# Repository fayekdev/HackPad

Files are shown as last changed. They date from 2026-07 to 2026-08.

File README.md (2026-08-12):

# **.devPAD**

An Elevated "SteamDeck" for developpers with fully customizable controls across many programs. I made it to make my life easier by having all of the most used tools and a way to properly move in CAD using the joystick in the middle. The e-ink screen is used as clock and a to-do list and could display the current media, volume level, microphone status and temperature.

***the tech stack***

 







## Screenshots

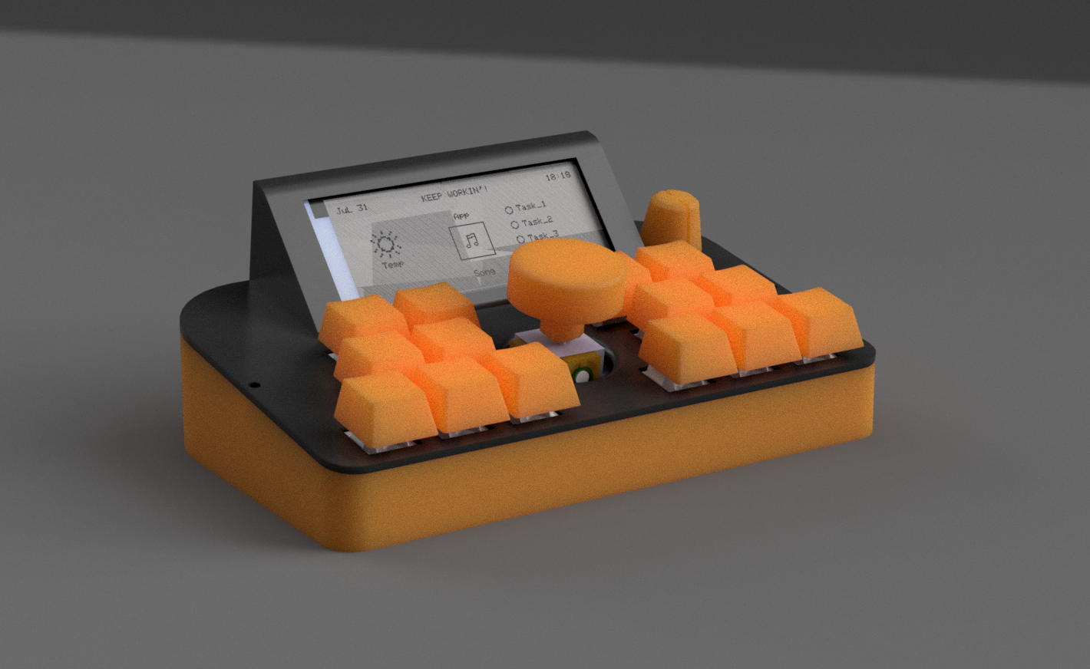
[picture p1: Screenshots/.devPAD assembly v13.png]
Render


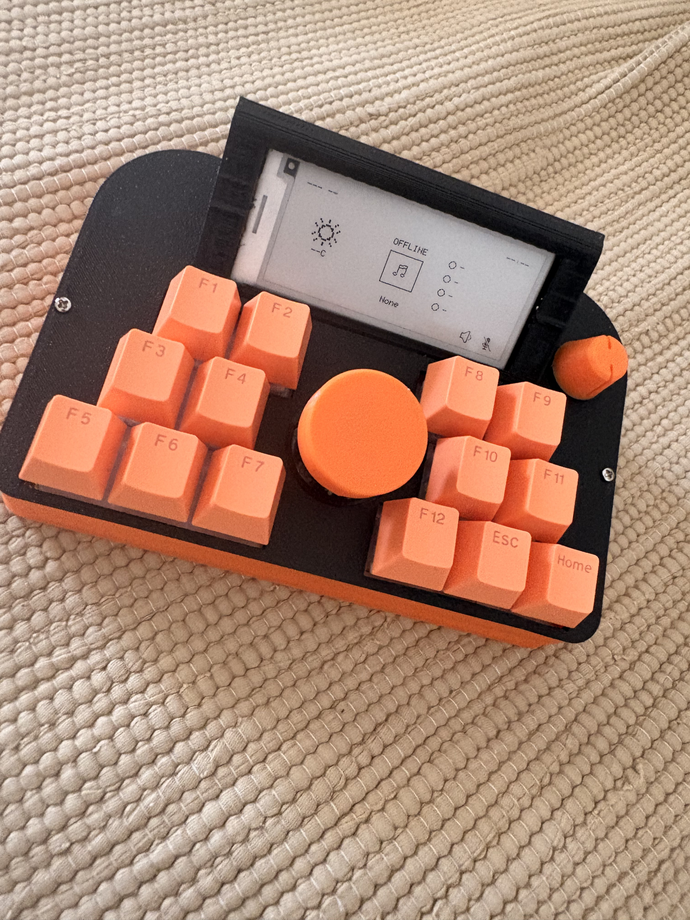
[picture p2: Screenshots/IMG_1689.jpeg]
Physical


## *THE CODE*

The code is still incomplete but still has ~80% functionality(only a few minor changes to make)

Currently working on the hardware problems so it is on delay

## *How was it made*  

- I designed the PCB in KiCAD and exported to Fusion to model the Case.

- The case was modeled and the components too to ensure the fit is correct

- Printed the first version 

- Fixed the errors in V1 and added a few features. 

- The PCB arrived and all components were test fit

- Began soldering the PCB 

- Fixed the errors I had made and uploaded a few test sketches.

- Test sketches were success and I tested the production code

- Production code worked out fine with a few problems

- A wire connected the screen to the microcontroller snapped and when trying to fix it a short-circuit happened and probably caused the microcontroller to malfunction.

*(The device only worked for 30 minutes or so before breaking)*

## *AI disclosure*

- AI was used as a research tool where I gave it all my requirements in one and it generated some sort of documentation that was held in it's context window so that when I ask a question or have a concern it automatically gives the answer I need instead of losing a ton of time researching myself

- Another usecase is the few errors I stumble upon that I spent a ton of time trying to fix I give to AI to give me a suggestion on how to fix it 

## Installation

Install the .devPAD desktop app --> 



Upload the **main.ino** sketch to the microcontroller

**SCREENSHOTS OF THE APP**

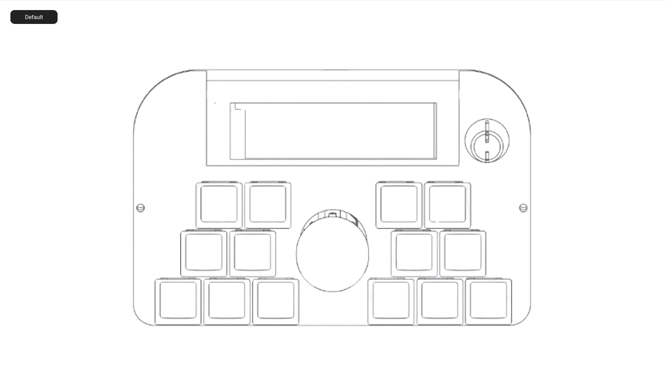
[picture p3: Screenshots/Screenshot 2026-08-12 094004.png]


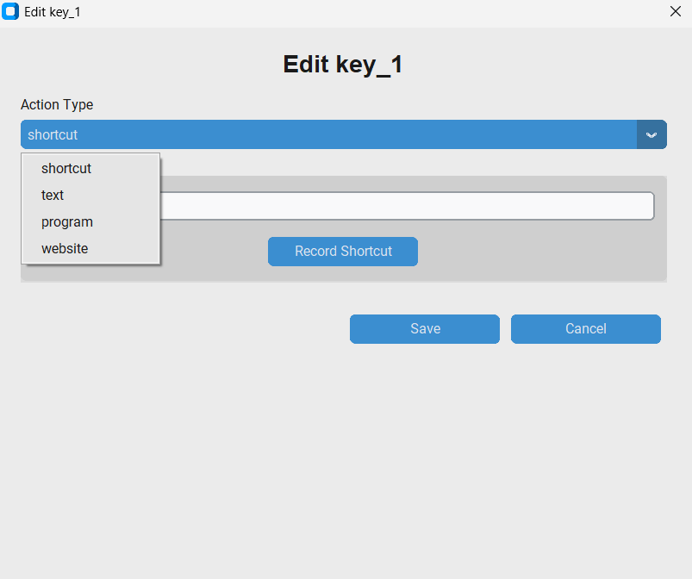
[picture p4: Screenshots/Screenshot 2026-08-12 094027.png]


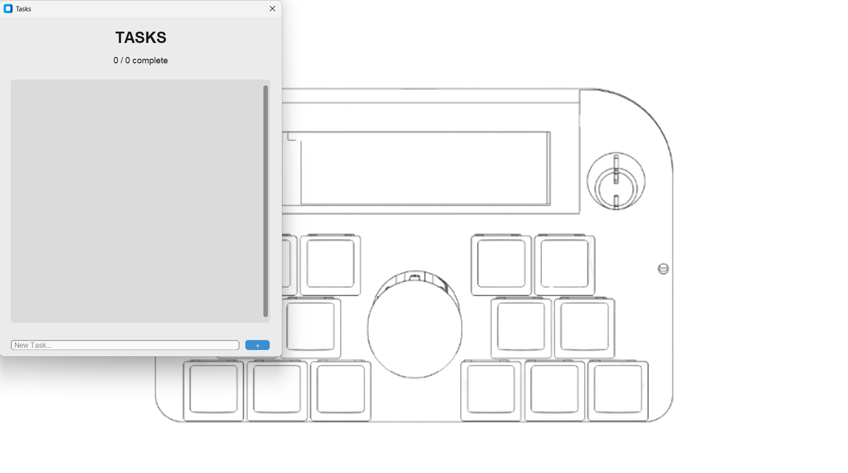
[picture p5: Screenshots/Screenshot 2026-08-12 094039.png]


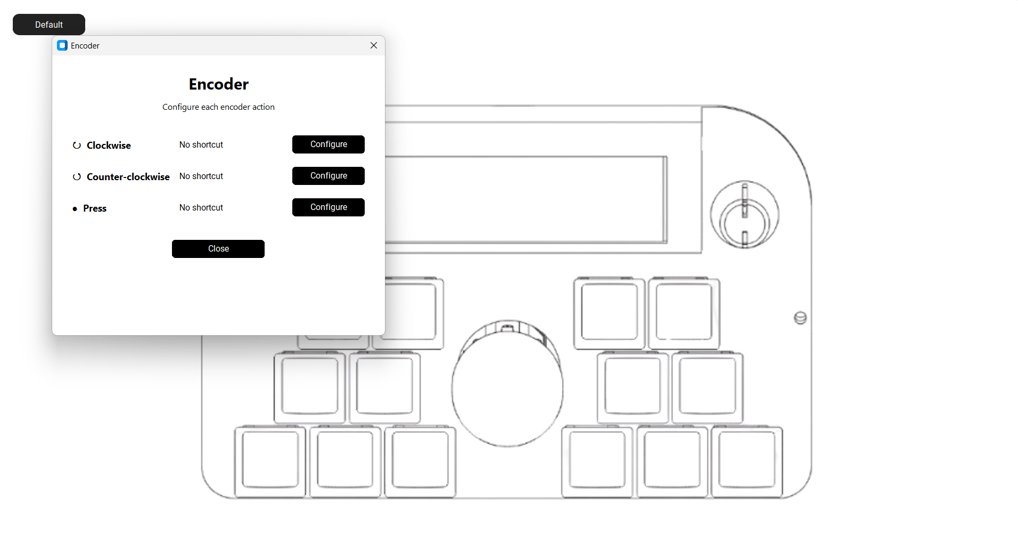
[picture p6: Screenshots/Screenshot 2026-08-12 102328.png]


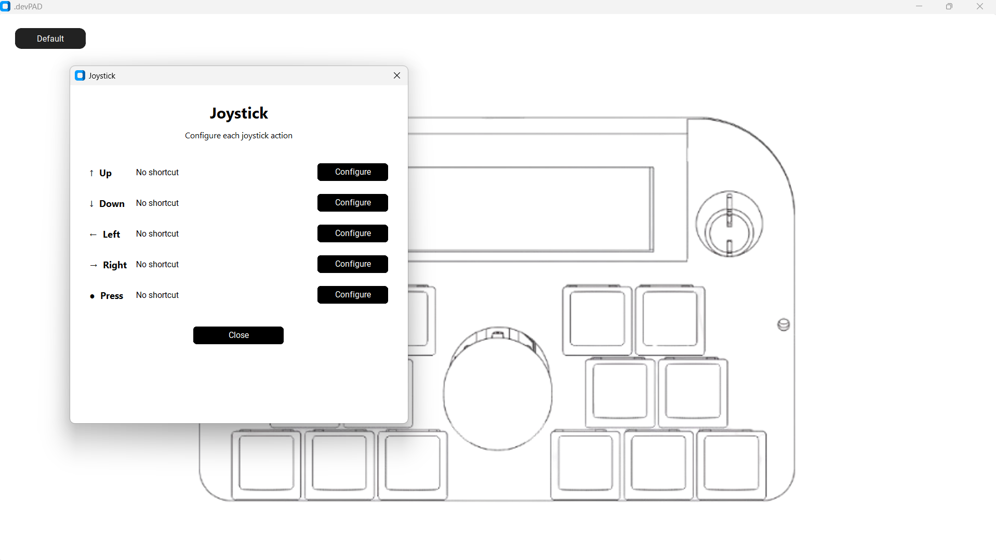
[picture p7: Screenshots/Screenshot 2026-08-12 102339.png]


## BOM

| Component | Qty |
| --- | --: |
|Xiao ESP32 C3 | 1  |
|  Keycaps |  14  |
|We-Act studio 2.9" E-ink screen | 1  |
| M2x6 screws | 8  |
|MX-Cherr Keyswitches | 14  |
| 1N4148 diodes |  16 |
| Rotary encoder |  1 |
| Joystick | 1  |
| Wire | (as much as you need)  |
| SN74HC595N |  1 |
|PCB|  1|

**TOOLS**

- Access to a 3D printer & filament
- Soldering tools 
- Wire strippers
- USB-C wire
- Arduino IDE

## Assembly GUIDE

1. Print all of the components. The face plate cover is optional (you should glue it if you want to use it)
---
2. Solder the first diode (under the joystick) upside down then solder the rest upright.
---
3. Solder the Joystick in its respective place but make sure it is properly level.
---
4. Solder the SN74HC595 and the Xiao ESP32 C3.
---
5. Solder all of the keyswitches.
---
7. Screw in the encoder and seat in the screen (if you want to make sure it's even more secure, use some tape instead of using the support beam).
---
8. Solder all of the encoder wires from the bottom and solder them to the encoder.
---
9. Solder the screen using it's respective connections using the 
schematic as a reference PS: The purple wire is not needed and the orange one should be wired up to the RST switch.
---
10. Seat the PCB and screw it in.
---
11. Close up the top plate being careful that the wires don't interfere with the USB port. You could put the USB-C wire in and close up the top plate to keep the wires from interfering
---
12. Add the joystick, the encoder knob and the 14 keycaps.
---
13. Upload the **main.ino** sketch via the Arduino IDE and run the ".devPAD" app
---

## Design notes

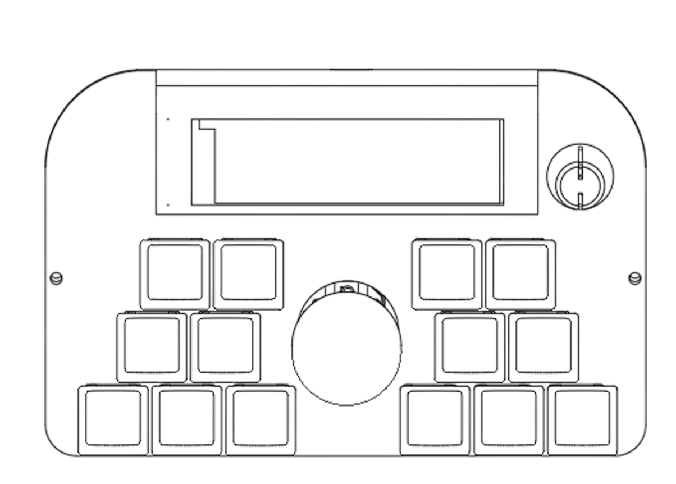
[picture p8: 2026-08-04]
Code/Software.devPAD/assets/HackPad.png

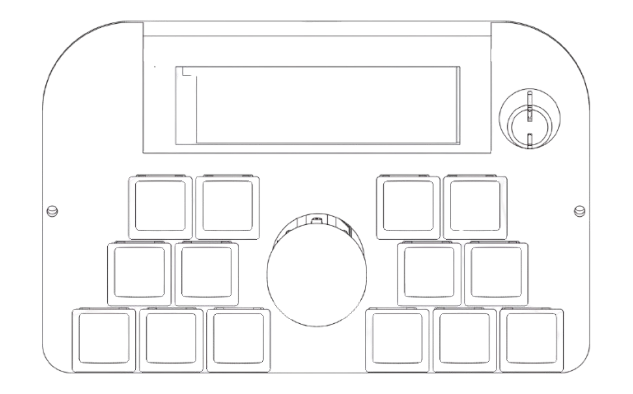
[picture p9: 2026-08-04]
Code/Software.devPAD/assets/image-removebg-preview.png

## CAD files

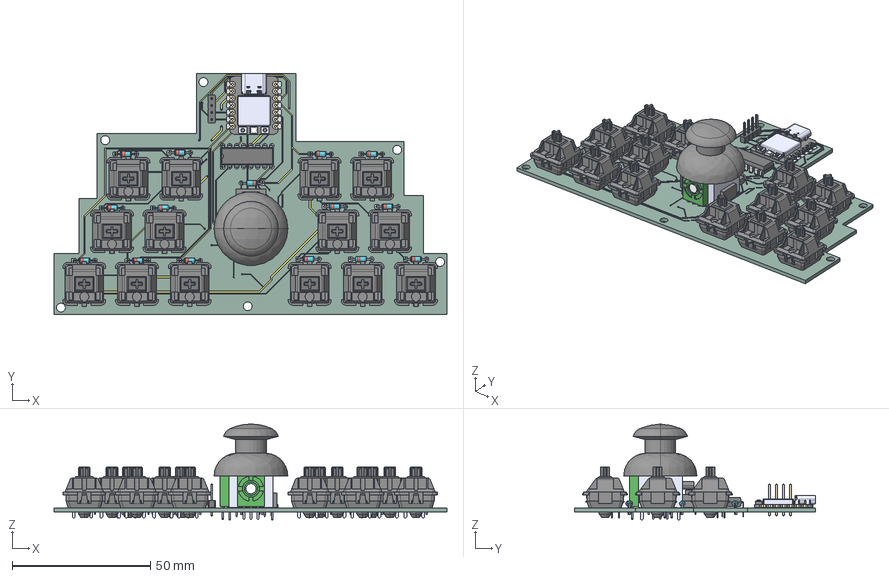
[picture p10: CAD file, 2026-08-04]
3d model.step
142.0 x 87.1 x 34.7 mm
D_DO-35_SOD27_P7.62mm_Horizontal x 16
MX1A-11NN x 14
PinHeader_1x04_P254mm_Vertical
DIP-16_W7.62mm
COM-09032
HackPad_copper
HackPad_pad
HackPad_via
HackPad_PCB

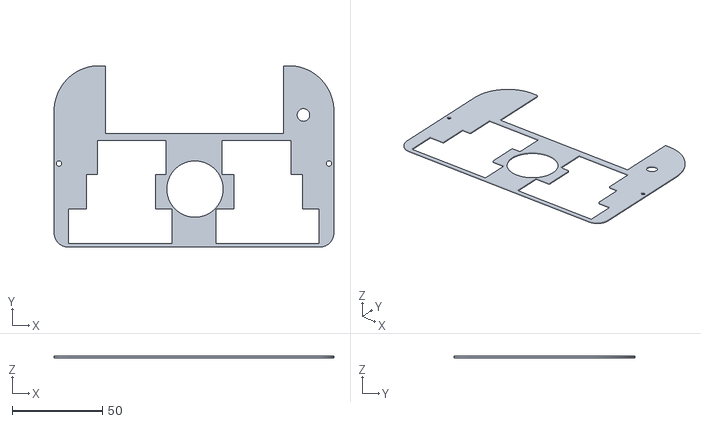
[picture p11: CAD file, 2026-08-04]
3d_models/STLs/FacePlateCover.stl
154.9 x 100.4 x 1.00

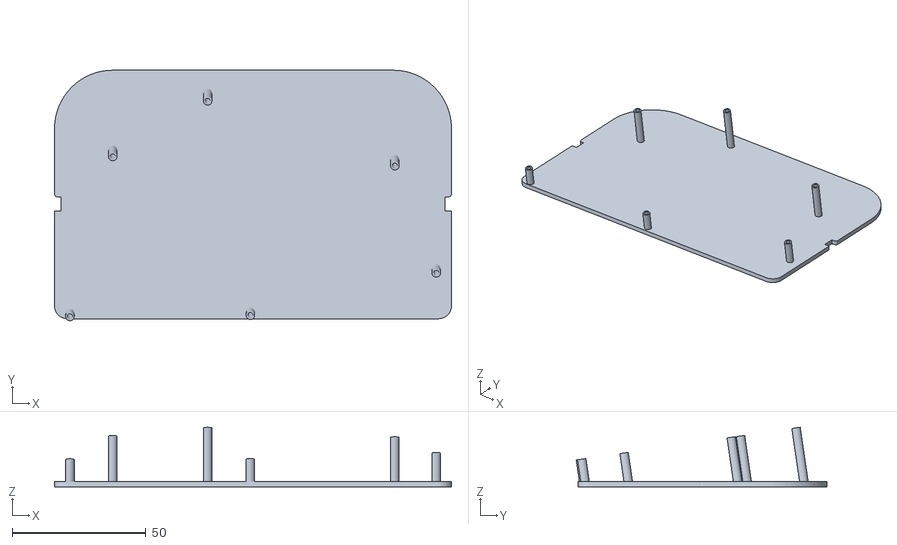
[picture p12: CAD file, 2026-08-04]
3d_models/STLs/Bottom_Standoffs.stl
148.5 x 93.7 x 22.3

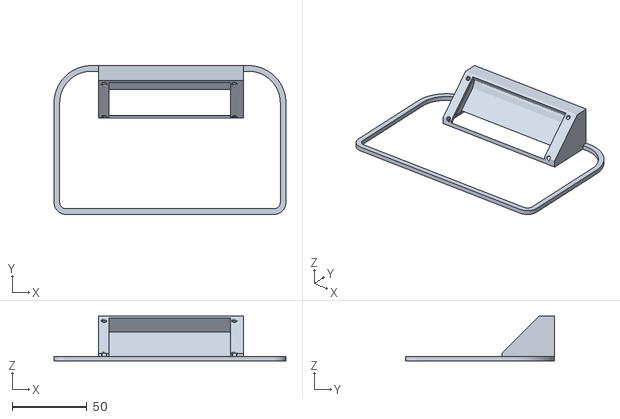
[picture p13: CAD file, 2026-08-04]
Body1.stl
154.9 x 99.4 x 30.0

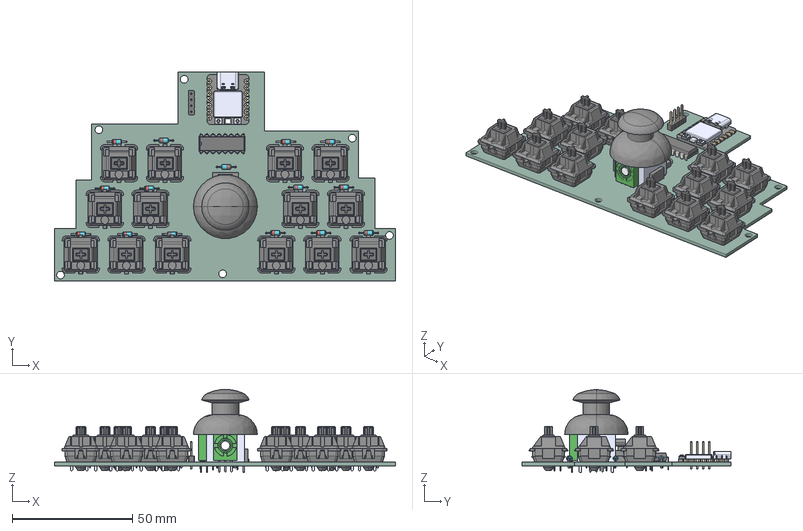
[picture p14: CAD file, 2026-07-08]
.step
142.0 x 87.1 x 34.7 mm
D_DO-35_SOD27_P7.62mm_Horizontal x 16
MX1A-11NN x 14
PinHeader_1x04_P254mm_Vertical
DIP-16_W7.62mm
COM-09032
HackPad_PCB

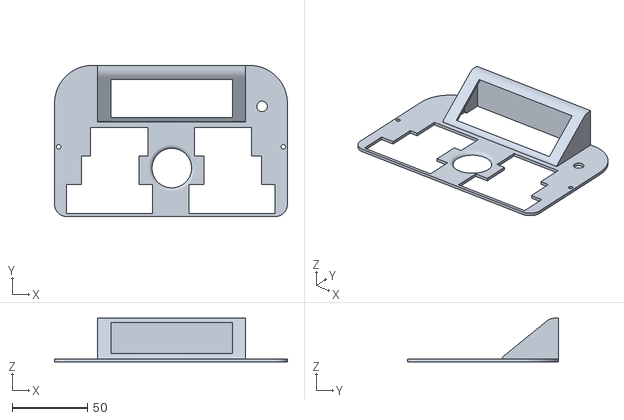
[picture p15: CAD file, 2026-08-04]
3d_models/STLs/Face_Plate.stl
154.9 x 100.4 x 29.0

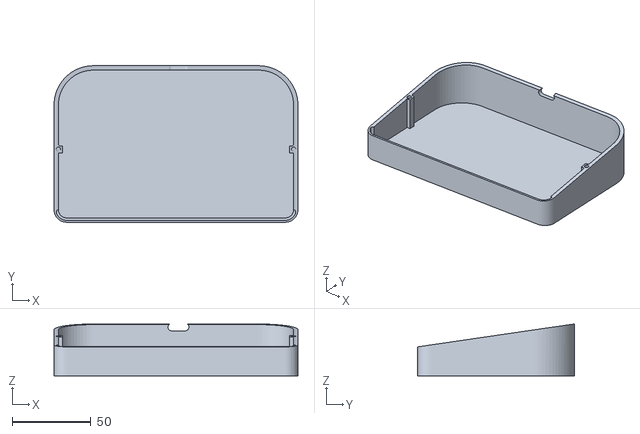
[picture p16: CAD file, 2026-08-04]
3d_models/STLs/Bottom_Case.stl
154.9 x 99.4 x 33.0

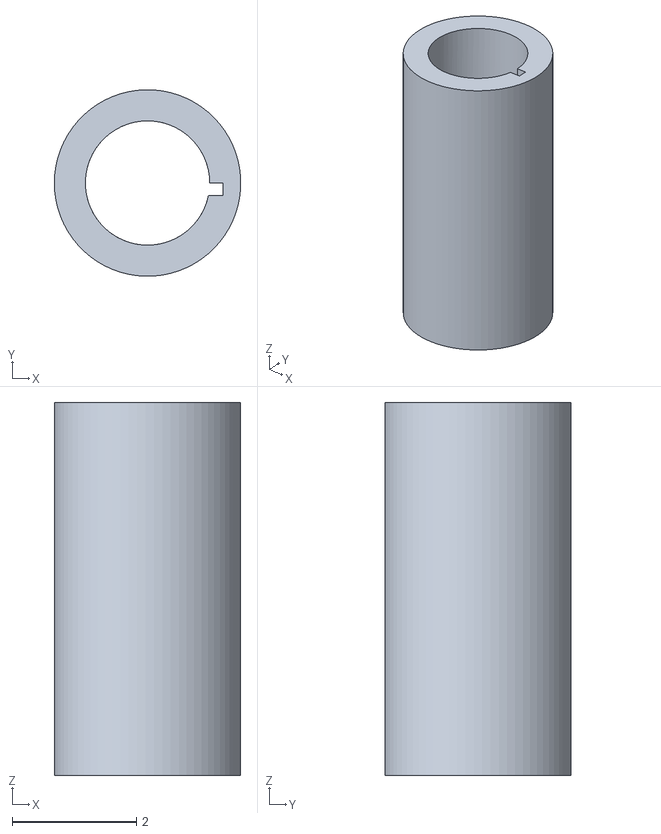
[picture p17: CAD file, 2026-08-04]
3d_models/STLs/PCB_Spacers.stl
3.00 x 3.00 x 6.00

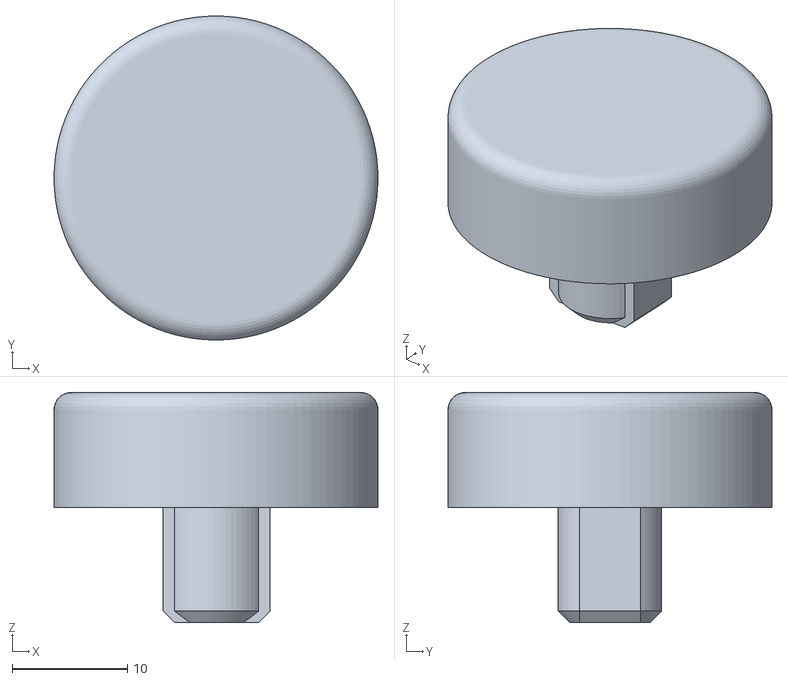
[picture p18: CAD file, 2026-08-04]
3d_models/STLs/Joystick.stl
28.2 x 28.2 x 20.0

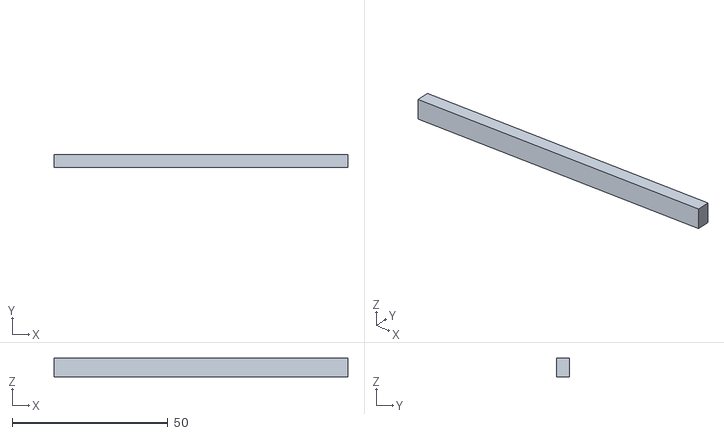
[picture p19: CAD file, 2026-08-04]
3d_models/STLs/Screen_Support.stl
94.5 x 4.09 x 6.00

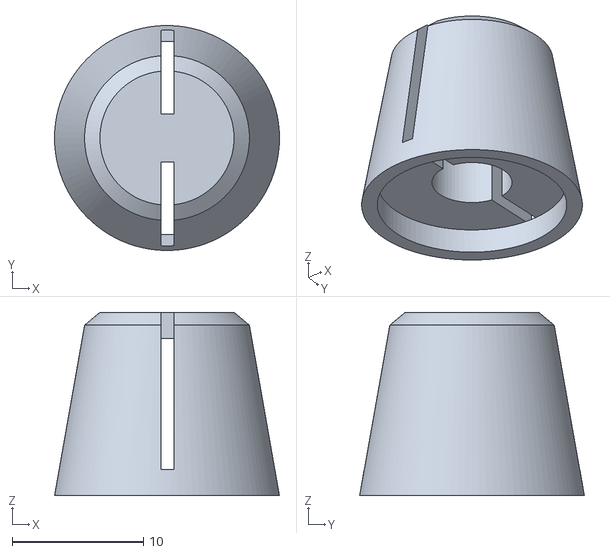
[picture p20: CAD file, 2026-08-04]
3d_models/STLs/Encoder_Knob.stl
17.2 x 17.2 x 14.0

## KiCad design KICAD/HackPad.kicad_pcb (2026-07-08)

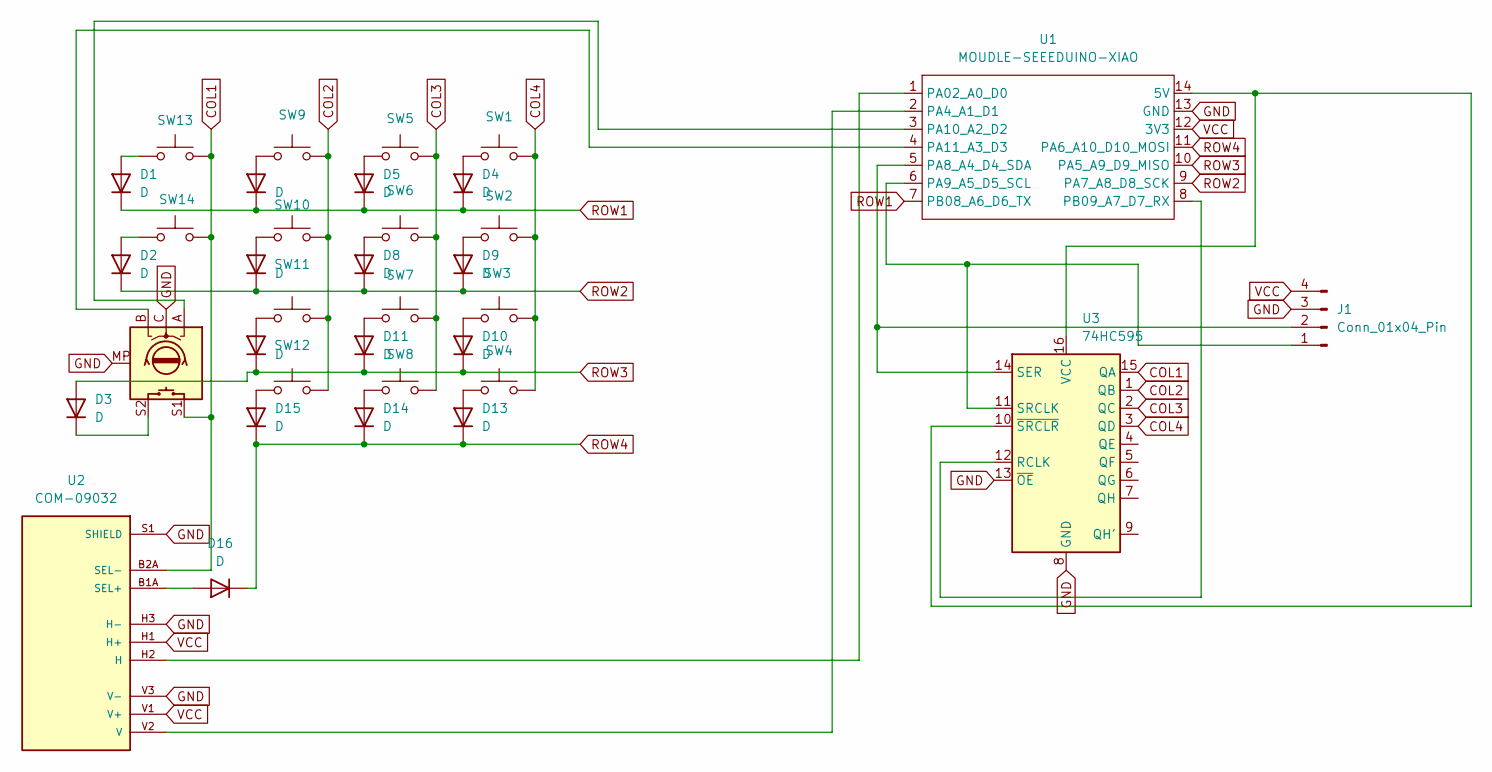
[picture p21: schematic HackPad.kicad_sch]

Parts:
D1, D2, D3, D4, D5, D6, D7, D8, D9, D10, D11, D12, D13, D14, D15, D16: D; D_DO-35_SOD27_P7.62mm_Horizontal
J1: Conn_01x04_Pin; PinHeader_1x04_P2.54mm_Vertical
SW1, SW2, SW3, SW4, SW5, SW6, SW7, SW8, SW9, SW10, SW11, SW12, SW13, SW14: SW_Push; SW_Cherry_MX_1.00u_PCB
SW15: RotaryEncoder_Switch_MP; RotaryEncoder_Alps_EC11E-Switch_Vertical_H20mm
U1: MOUDLE-SEEEDUINO-XIAO; MCU_Seeed_ESP32C3
U2: COM-09032; XDCR_COM-09032; PARTREV N/A
U3: 74HC595; DIP-16_W7.62mm

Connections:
COL1: SW13.2, SW14.2, SW15.S1, U2.B2A (SEL-), U3.15 (QA)
COL2: SW9.2, SW10.2, SW11.2, SW12.2, U3.1 (QB)
COL3: SW5.2, SW6.2, SW7.2, SW8.2, U3.2 (QC)
COL4: SW1.2, SW2.2, SW3.2, SW4.2, U3.3 (QD)
GND: J1.3, SW15.C, SW15.MP, U1.13 (GND), U2.H3 (H-), U2.S1 (SHIELD), U2.S2 (SHIELD), U2.S3 (SHIELD), U2.S4 (SHIELD), U2.V3 (V-), U3.8 (GND), U3.13 (~OE)
unnamed: D1.2 (A), SW13.1
unnamed: D2.2 (A), SW14.1
unnamed: D3.1 (K), SW15.S2
unnamed: D4.2 (A), SW1.1
unnamed: D5.2 (A), SW5.1
unnamed: D6.2 (A), SW9.1
unnamed: D7.2 (A), SW10.1
unnamed: D8.2 (A), SW6.1
unnamed: D9.2 (A), SW2.1
unnamed: D10.2 (A), SW3.1
unnamed: D11.2 (A), SW7.1
unnamed: D12.2 (A), SW11.1
unnamed: D13.2 (A), SW4.1
unnamed: D14.2 (A), SW8.1
unnamed: D15.2 (A), SW12.1
unnamed: D16.2 (A), U2.B1A (SEL+)
unnamed: J1.1, U1.6 (PA9_A5_D5_SCL), U3.11 (SRCLK)
unnamed: J1.2, U1.5 (PA8_A4_D4_SDA), U3.14 (SER)
unnamed: U1.14 (5V), U3.10 (~SRCLR), U3.16 (VCC)
unnamed: U1.1 (PA02_A0_D0), U2.H2 (H)
unnamed: U1.2 (PA4_A1_D1), U2.V2 (V)
unnamed: SW15.A, U1.3 (PA10_A2_D2)
unnamed: SW15.B, U1.4 (PA11_A3_D3)
unnamed: U1.8 (PB09_A7_D7_RX), U3.12 (RCLK)
ROW1: D1.1 (K), D4.1 (K), D5.1 (K), D6.1 (K), U1.7 (PB08_A6_D6_TX)
ROW2: D2.1 (K), D7.1 (K), D8.1 (K), D9.1 (K), U1.9 (PA7_A8_D8_SCK)
ROW3: D3.2 (A), D10.1 (K), D11.1 (K), D12.1 (K), U1.10 (PA5_A9_D9_MISO)
ROW4: D13.1 (K), D14.1 (K), D15.1 (K), D16.1 (K), U1.11 (PA6_A10_D10_MOSI)
VCC: J1.4, U1.12 (3V3), U2.H1 (H+), U2.V1 (V+)

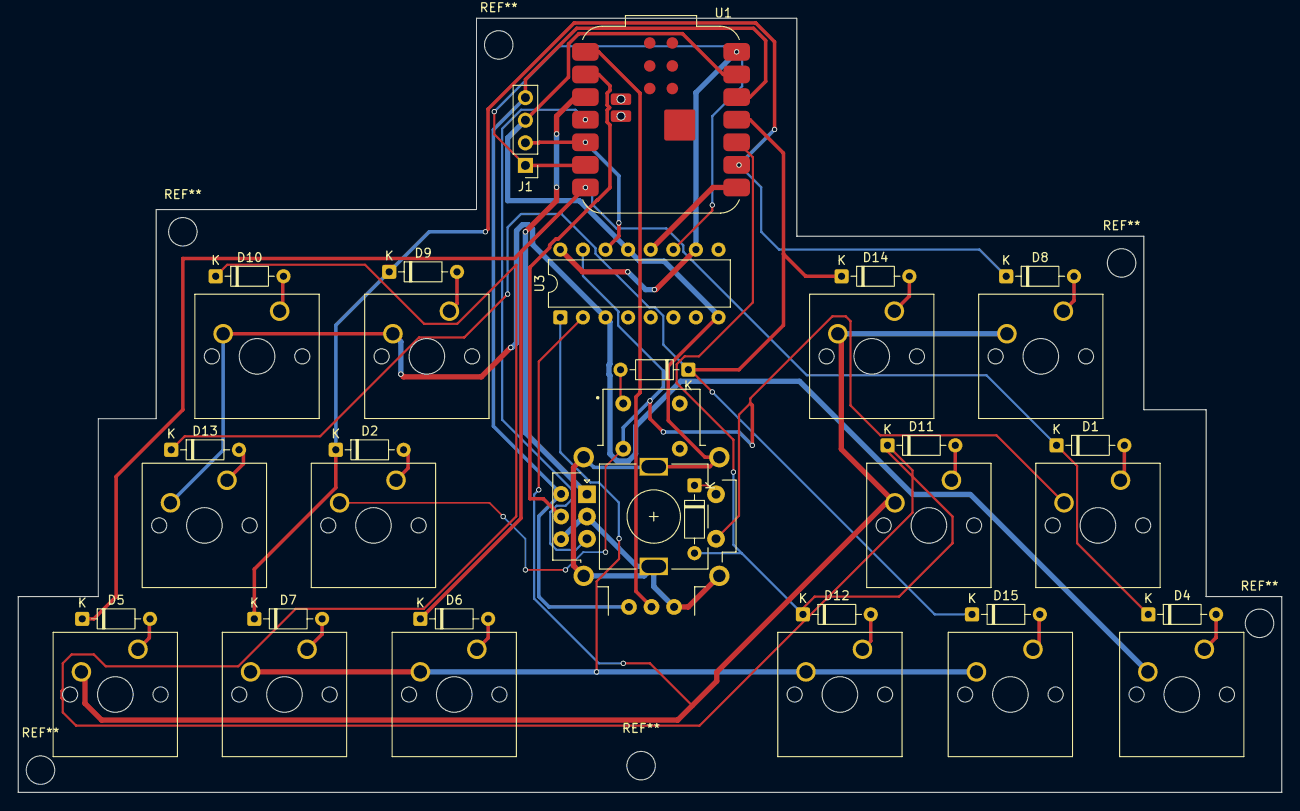
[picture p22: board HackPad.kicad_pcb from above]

Board: 2 copper layers, 142.0 x 87.0 mm, 35 parts (0 on the bottom side), 34 nets.

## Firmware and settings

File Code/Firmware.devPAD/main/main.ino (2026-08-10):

#include <GxEPD2_BW.h>
#include <Adafruit_GFX.h>
#include <SPI.h>

#define EPD_CS    20
#define EPD_DC    3
#define EPD_RST   4
#define EPD_BUSY  -1

#define EPD_SCK   7
#define EPD_MOSI  6

#define SR_PL_LATCH 2
#define SR_CLK      1
#define SR_DATA_IN  0

#define ENC_CLK     4
#define ENC_DT      5

#define JOY_X       10
#define JOY_Y       21

enum DynamicField {
    FIELD_TIME,
    FIELD_APP,
    FIELD_MUSIC,
    FIELD_WEATHER,
    FIELD_HARDWARE,
    FIELD_TASKS
};

GxEPD2_BW<GxEPD2_290_T94, GxEPD2_290_T94::HEIGHT> display(
    GxEPD2_290_T94(EPD_CS, EPD_DC, EPD_RST, EPD_BUSY)
);

String string_1_text = "--:--";
String string_3_text = "OFFLINE";
String string_4_text = "None";
String string_9_text = "--- --";
String string_17_text = "--C";

String string_11_text = "-";
String string_11_copy_1_text = "-";
String state_task3 = "-";
String state_task4 = "-";

String state_weather = "Sunny";
String state_sound = "low";
String state_mic = "off";

String lastTimeText;
String lastAppText;
String lastMusicText;
String lastDateText;
String lastTempText;
String lastWeatherText;
String lastSoundText;
String lastMicText;
String lastTask1Text;
String lastTask2Text;
String lastTask3Text;
String lastTask4Text;

bool buttons[16] = {false};

int last_enc_CLK = LOW;
long encoder_pos = 0;

unsigned long lastUpdateTime = 0;
unsigned long last_pc_packet_time = 0;

const unsigned long updateInterval = 1000;
const unsigned long pcTimeout = 3500;

bool is_pc_connected = false;

int partialRefreshCounter = 0;
const int maxPartialRefreshes = 60;

void drawScreen_Full();
void drawStaticLayout();
void drawAllFields();
void updateDynamicField(DynamicField field);

String extractField(const String &src, const char *tag)
{
    int start = src.indexOf(tag);

    if (start < 0)
        return "";

    start += strlen(tag);

    int end = src.indexOf('|', start);

    if (end < 0)
        end = src.length();

    return src.substring(start, end);
}

void setup()
{
    Serial.begin(115200);
    Serial.setTimeout(50);

    pinMode(SR_PL_LATCH, OUTPUT);
    pinMode(SR_CLK, OUTPUT);
    pinMode(SR_DATA_IN, INPUT);

    digitalWrite(SR_PL_LATCH, HIGH);
    digitalWrite(SR_CLK, LOW);

    pinMode(ENC_CLK, INPUT_PULLUP);
    pinMode(ENC_DT, INPUT_PULLUP);

    last_enc_CLK = digitalRead(ENC_CLK);

    SPI.begin(EPD_SCK, -1, EPD_MOSI, EPD_CS);

    display.init(115200, true, 2, false);
    display.setRotation(3);

    drawScreen_Full();
}

void loop()
{
    unsigned long currentMillis = millis();

    bool button_changed = false;
    bool encoder_changed = false;

    digitalWrite(SR_PL_LATCH, LOW);
    delayMicroseconds(5);
    digitalWrite(SR_PL_LATCH, HIGH);

    for (int i = 0; i < 16; i++)
    {
        bool raw_val = !digitalRead(SR_DATA_IN);

        digitalWrite(SR_CLK, HIGH);
        delayMicroseconds(2);
        digitalWrite(SR_CLK, LOW);

        if (buttons[i] != raw_val)
        {
            buttons[i] = raw_val;
            button_changed = true;
        }
    }

    int current_enc_CLK = digitalRead(ENC_CLK);

    if (current_enc_CLK != last_enc_CLK &&
        current_enc_CLK == LOW)
    {
        if (digitalRead(ENC_DT) != current_enc_CLK)
            encoder_pos++;
        else
            encoder_pos--;

        encoder_changed = true;
    }

    last_enc_CLK = current_enc_CLK;

    int joyX = analogRead(JOY_X);
    int joyY = analogRead(JOY_Y);

    if (Serial.available())
    {
        String input = Serial.readStringUntil('\n');
        input.trim();

        if (input.startsWith("HELLO"))
        {
            last_pc_packet_time = currentMillis;

            if (!is_pc_connected)
            {
                is_pc_connected = true;
                drawScreen_Full();
            }
        }
        else if (input.startsWith("DATA:"))
        {
            last_pc_packet_time = currentMillis;
            is_pc_connected = true;

            String value;

            value = extractField(input, "|APP:");
            if (value.length())
                string_3_text = value;

            value = extractField(input, "|WEA:");
            if (value.length())
                state_weather = value;

            value = extractField(input, "|TMP:");
            if (value.length())
                string_17_text = value;

            value = extractField(input, "|SND:");
            if (value.length())
                state_sound = value;

            value = extractField(input, "|MIC:");
            if (value.length())
                state_mic = value;

            value = extractField(input, "|SNG:");
            if (value.length())
                string_4_text = value;

            value = extractField(input, "|DAT:");
            if (value.length())
                string_9_text = value;

            value = extractField(input, "|TIM:");
            if (value.length())
                string_1_text = value;

            value = extractField(input, "|T1:");
            if (value.length())
                string_11_text = value;

            value = extractField(input, "|T2:");
            if (value.length())
                string_11_copy_1_text = value;

            value = extractField(input, "|T3:");
            if (value.length())
                state_task3 = value;

            value = extractField(input, "|T4:");
            if (value.length())
                state_task4 = value;
        }
    }

    if (currentMillis - lastUpdateTime >= updateInterval)
    {
        lastUpdateTime = currentMillis;

        bool timeChanged =
            string_1_text != lastTimeText;

        bool appChanged =
            string_3_text != lastAppText;

        bool musicChanged =
            string_4_text != lastMusicText;

        bool dateChanged =
            string_9_text != lastDateText;

        bool tempChanged =
            string_17_text != lastTempText;

        bool weatherChanged =
            state_weather != lastWeatherText;

        bool soundChanged =
            state_sound != lastSoundText;

        bool micChanged =
            state_mic != lastMicText;

        bool tasksChanged =
            string_11_text != lastTask1Text ||
            string_11_copy_1_text != lastTask2Text ||
            state_task3 != lastTask3Text ||
            state_task4 != lastTask4Text;

        bool anythingChanged =
            timeChanged ||
            appChanged ||
            musicChanged ||
            dateChanged ||
            tempChanged ||
            weatherChanged ||
            soundChanged ||
            micChanged ||
            tasksChanged;

        if (anythingChanged)
        {
            if (partialRefreshCounter >= maxPartialRefreshes)
            {
                drawScreen_Full();
                partialRefreshCounter = 0;
            }
            else
            {
                if (timeChanged)
                    updateDynamicField(FIELD_TIME);

                if (appChanged)
                    updateDynamicField(FIELD_APP);

                if (musicChanged)
                    updateDynamicField(FIELD_MUSIC);

                if (dateChanged)
                    updateDynamicField(FIELD_WEATHER);

                if (tempChanged)
                    updateDynamicField(FIELD_WEATHER);

                if (weatherChanged)
                    updateDynamicField(FIELD_WEATHER);

                if (soundChanged || micChanged)
                    updateDynamicField(FIELD_HARDWARE);

                if (tasksChanged)
                    updateDynamicField(FIELD_TASKS);

                partialRefreshCounter++;
            }

            lastTimeText = string_1_text;
            lastAppText = string_3_text;
            lastMusicText = string_4_text;
            lastDateText = string_9_text;
            lastTempText = string_17_text;
            lastWeatherText = state_weather;
            lastSoundText = state_sound;
            lastMicText = state_mic;
            lastTask1Text = string_11_text;
            lastTask2Text = string_11_copy_1_text;
            lastTask3Text = state_task3;
            lastTask4Text = state_task4;
        }
    }

    if (is_pc_connected &&
        currentMillis - last_pc_packet_time > pcTimeout)
    {
        is_pc_connected = false;

        string_1_text = "--:--";
        string_3_text = "OFFLINE";
        string_4_text = "None";
        string_9_text = "--- --";
        string_17_text = "--C";

        string_11_text = "-";
        string_11_copy_1_text = "-";
        state_task3 = "-";
        state_task4 = "-";

        state_weather = "Sunny";
        state_sound = "low";
        state_mic = "off";

        drawScreen_Full();
        partialRefreshCounter = 0;
    }

    if (is_pc_connected)
    {
        static unsigned long last_tx = 0;

        if (currentMillis - last_tx > 40 ||
            button_changed ||
            encoder_changed)
        {
            last_tx = currentMillis;

            Serial.print("{\"joyX\":");
            Serial.print(joyX);

            Serial.print(",\"joyY\":");
            Serial.print(joyY);

            Serial.print(",\"encoder\":");
            Serial.print(encoder_pos);

            Serial.print(",\"buttons\":[");

            for (int i = 0; i < 16; i++)
            {
                Serial.print(buttons[i] ? "1" : "0");

                if (i < 15)
                    Serial.print(",");
            }

            Serial.println("]}");
        }
    }

    delay(5);
}

void drawScreen_Full()
{
    display.setFullWindow();
    display.firstPage();

    do
    {
        display.fillScreen(GxEPD_WHITE);

        drawStaticLayout();
        drawAllFields();

    } while (display.nextPage());
}

void drawStaticLayout()
{
    display.setTextSize(1);
    display.setTextColor(GxEPD_BLACK);
    display.setTextWrap(false);

    display.setCursor(107, 12);
    display.print("KEEP WORKIN'!");

    display.drawRect(
        123,
        51,
        41,
        38,
        GxEPD_BLACK
    );

    display.drawCircle(197, 43, 4, GxEPD_BLACK);
    display.drawCircle(197, 60, 4, GxEPD_BLACK);
    display.drawCircle(197, 77, 4, GxEPD_BLACK);
    display.drawCircle(197, 95, 4, GxEPD_BLACK);
}

void drawAllFields()
{
    display.setTextSize(1);
    display.setTextColor(GxEPD_BLACK);
    display.setTextWrap(false);

    display.setCursor(10, 11);
    display.print(string_9_text);

    display.setCursor(254, 11);
    display.print(string_1_text);

    display.setCursor(134, 37);
    display.print(string_3_text);

    display.drawBitmap(
        135,
        62,
        image_music_bits,
        14,
        16,
        GxEPD_BLACK
    );

    display.setCursor(132, 102);
    display.print(string_4_text);

    display.setCursor(207, 39);
    display.print(string_11_text);

    display.setCursor(207, 57);
    display.print(string_11_copy_1_text);

    display.setCursor(207, 74);
    display.print(state_task3);

    display.setCursor(207, 92);
    display.print(state_task4);

    drawHardwareIcons();
    drawWeather();
}

void drawHardwareIcons()
{
    if (state_sound.equalsIgnoreCase("loud"))
    {
        display.drawBitmap(
            240,
            109,
            image_volume_loud_bits,
            20,
            16,
            GxEPD_BLACK
        );
    }
    else
    {
        display.drawBitmap(
            240,
            109,
            image_volume_low_bits,
            18,
            16,
            GxEPD_BLACK
        );
    }

    if (state_mic.equalsIgnoreCase("on"))
    {
        display.drawBitmap(
            267,
            109,
            image_microphone_1_bits,
            15,
            16,
            GxEPD_BLACK
        );
    }
    else
    {
        display.drawBitmap(
            268,
            109,
            image_microphone_muted_bits,
            15,
            16,
            GxEPD_BLACK
        );
    }
}

void drawWeather()
{
    if (state_weather.equalsIgnoreCase("Sunny"))
    {
        display.drawBitmap(
            34,
            43,
            image_weather_sun_bits,
            30,
            32,
            GxEPD_BLACK
        );
    }
    else
    {
        display.drawBitmap(
            34,
            43,
            image_weather_sun_bits,
            30,
            32,
            GxEPD_BLACK
        );
    }

    display.setCursor(37, 77);
    display.print(string_17_text);
}

void updateDynamicField(DynamicField field)
{
    uint16_t x = 0;
    uint16_t y = 0;
    uint16_t w = 0;
    uint16_t h = 0;

    switch (field)
    {
        case FIELD_TIME:
            x = 248;
            y = 3;
            w = 48;
            h = 14;
            break;

        case FIELD_APP:
            x = 130;
            y = 30;
            w = 166;
            h = 15;
            break;

        case FIELD_MUSIC:
            x = 128;
            y = 98;
            w = 168;
            h = 16;
            break;

        case FIELD_WEATHER:
            x = 30;
            y = 39;
            w = 38;
            h = 42;
            break;

        case FIELD_HARDWARE:
            x = 237;
            y = 106;
            w = 59;
            h = 21;
            break;

        case FIELD_TASKS:
            x = 204;
            y = 34;
            w = 91;
            h = 65;
            break;
    }

    display.setPartialWindow(x, y, w, h);

    display.firstPage();

    do
    {
        display.fillRect(
            x,
            y,
            w,
            h,
            GxEPD_WHITE
        );

        display.setTextSize(1);
        display.setTextColor(GxEPD_BLACK);
        display.setTextWrap(false);

        switch (field)
        {
            case FIELD_TIME:
                display.setCursor(254, 11);
                display.print(string_1_text);
                break;

            case FIELD_APP:
                display.setCursor(134, 37);
                display.print(string_3_text);
                break;

            case FIELD_MUSIC:
                display.setCursor(132, 102);
                display.print(string_4_text);
                break;

            case FIELD_WEATHER:
                drawWeather();
                break;

            case FIELD_HARDWARE:
                drawHardwareIcons();
                break;

            case FIELD_TASKS:
                display.setCursor(207, 39);
                display.print(string_11_text);

                display.setCursor(207, 57);
                display.print(string_11_copy_1_text);

                display.setCursor(207, 74);
                display.print(state_task3);

                display.setCursor(207, 92);
                display.print(state_task4);
                break;
        }

    } while (display.nextPage());
}

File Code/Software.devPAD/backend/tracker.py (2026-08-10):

import os
import sys
import json
import time
import serial
import threading
import asyncio
import webbrowser

import pyautogui
import requests

from ctypes import cast, POINTER
from comtypes import CLSCTX_ALL
from pycaw.pycaw import AudioUtilities, IAudioEndpointVolume

from winrt.windows.media.control import (
    GlobalSystemMediaTransportControlsSessionManager as MediaManager
)

try:
    import pygetwindow as gw
except ImportError:
    gw = None


pyautogui.FAILSAFE = True
pyautogui.PAUSE = 0.01

CONFIG_FILE = "profiles.json"
SERIAL_PORT = "COM15"
BAUD_RATE = 115200


def load_profiles():
    if os.path.exists(CONFIG_FILE):
        try:
            with open(CONFIG_FILE, "r", encoding="utf-8") as f:
                data = json.load(f)

            if isinstance(data, dict):
                return data

        except Exception:
            pass

    return {
        "Default": {
            "buttons": {},
            "encoder": {},
            "joystick": {},
            "todos": ["", "", "", ""]
        }
    }


class HackPadSystemTracker:

    def __init__(self):
        self.profiles = load_profiles()
        self.current_profile_name = "Default"

        self.running = True
        self.pc_link_active = False

        self.joystick_x = 512
        self.joystick_y = 512
        self.buttons_state = [0] * 16
        self.encoder_pos = 0

        self.DEADZONE = 40
        self.CENTER = 512
        self.CURSOR_SPEED_MODIFIER = 0.04

        self.speaker_volume = None
        self.microphone_volume = None

        self.current_song_title = "Idle"

        self.weather_state = "Sunny"
        self.temp_state = "21C"

        self.init_system_audio()
        self.start_weather_thread()
        self.start_media_tracking_thread()

    def init_system_audio(self):
        try:
            devices = AudioUtilities.GetDeviceEnumerator()

            speakers = getattr(
                devices,
                "GetDefaultAudioEndpoint"
            )(0, 0)

            self.speaker_volume = cast(
                speakers.Activate(
                    IAudioEndpointVolume._iid_,
                    CLSCTX_ALL,
                    None
                ),
                POINTER(IAudioEndpointVolume)
            )

            microphones = getattr(
                devices,
                "GetDefaultAudioEndpoint"
            )(1, 0)

            self.microphone_volume = cast(
                microphones.Activate(
                    IAudioEndpointVolume._iid_,
                    CLSCTX_ALL,
                    None
                ),
                POINTER(IAudioEndpointVolume)
            )

            print("[+] Audio subsystem hooks attached successfully.")

        except Exception as e:
            print(f"[-] Sound hardware hook failed: {e}")

    async def get_windows_media_properties(self):
        try:
            sessions = await MediaManager.request_async()
            current_session = sessions.get_current_session()

            if current_session:
                info = await current_session.try_get_media_properties_async()

                if info:
                    title = info.title if info.title else "Unknown"
                    artist = info.artist if info.artist else "Unknown"

                    combined = f"{title} - {artist}"

                    if len(combined) > 14:
                        return combined[:13] + ".."

                    return combined

            return "No Media"

        except Exception:
            return "Idle"

    def run_media_update_loop(self):
        loop = asyncio.new_event_loop()
        asyncio.set_event_loop(loop)

        try:
            while self.running:
                self.current_song_title = loop.run_until_complete(
                    self.get_windows_media_properties()
                )

                time.sleep(2.0)

        finally:
            loop.close()

    def start_media_tracking_thread(self):
        threading.Thread(
            target=self.run_media_update_loop,
            daemon=True
        ).start()

    def fetch_live_weather(self):
        print(
            "[+] Weather tracking system background thread initialized."
        )

        headers = {
            "User-Agent":
                "Mozilla/5.0 (Windows NT 10.0; Win64; x64) "
                "AppleWebKit/537.36"
        }

        while self.running:
            try:
                response = requests.get(
                    "https://wttr.in?format=j1",
                    headers=headers,
                    timeout=(3.5, 5)
                )

                if response.status_code == 200:
                    data = response.json()

                    conditions = data.get(
                        "current_condition",
                        []
                    )

                    if isinstance(conditions, list) and conditions:
                        current = conditions[0]

                        feels_like = current.get(
                            "FeelsLikeC",
                            "21"
                        )

                        self.temp_state = f"{feels_like}C"

                        desc_text = "sunny"

                        descriptions = current.get(
                            "weatherDesc",
                            []
                        )

                        if (
                            isinstance(descriptions, list)
                            and descriptions
                        ):
                            desc_text = descriptions[0].get(
                                "value",
                                "sunny"
                            ).lower()

                        if any(
                            word in desc_text
                            for word in [
                                "rain",
                                "drizzle",
                                "shower",
                                "thunderstorm",
                                "sleet"
                            ]
                        ):
                            self.weather_state = "Rainy"

                        elif any(
                            word in desc_text
                            for word in [
                                "cloud",
                                "overcast",
                                "mist",
                                "fog",
                                "haze"
                            ]
                        ):
                            self.weather_state = "Cloudy"
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

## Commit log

2026-07-05 Added USB port and completed the joystick connections.
    [HackPad.kicad_sch]
2026-07-07 Finished the whole schematic. Started the PCB design.
    [HackPad.kicad_pcb, HackPad.kicad_sch]
2026-07-07 Finished the whole schematic. Started the PCB layout
    [HackPad.kicad_pcb]
2026-07-07 Finished the PCB completely
    [HackPad.kicad_pcb]
2026-07-08 Exported 3d models in .step and .stl for 3D modeling in Fusion. These models will be used as a reference for modeling
    [.step, HackPad.kicad_pcb]
2026-08-04 Commits didn't work!!! I added the FInal STL of the project and the GCODE. Started the Firmware (bare minimum) and the Software with all of the features
    [3d model.step, Body1.stl, Bottom_Case.stl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]
2026-08-04 rest of previous commit
    [Bottom_Standoffs.stl, FacePlateCover.stl, Face_Plate.stl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]
2026-08-12 Add README for .devPAD projectAdde
    Added detailed documentation for the .devPAD project, including features, installation instructions, assembly guide, and bill of materials.
